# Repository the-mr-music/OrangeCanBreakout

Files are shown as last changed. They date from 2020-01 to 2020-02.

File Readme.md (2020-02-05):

# Orange PI CAN Breakout


T. Music - 01/2020

## Project Status

```
PCB Design Complete - Next up is assembly and testing
```

## Introduction

Some time ago I had ordered myself a Raspberry Pi Zero with the intention to use it as a wireless debugger. The performance of it and the system in general however did not live up to my expected standards, so I had decided to give another single board computer a shot. The requirements whilst picking were easy integreatibility (USB on pinheaders), sufficiently high computational power (something the rpi zero somewhat lacked) and naturally - WiFi. In the end the Orange Pi Zero Plus 2 (Allwinner H5 core) won and was ordered.

On top of that I thought about extending the capability of said system through optional modules, which can be addressed through a python api running on the orange pi. One criteria was to provide somewhat sufficient data rate for hobbyist use cases and to keep the hardware overhead low. After reading through a few bus systems and protocols I reached the decision to use CAN bus. Cheap controllers by ST have already CAN controllers built in and require only a transceiver in the range of a few cents. These STM32 support data rates up to 1 Mbit/s, enough for small amounts of measurement data as well as control messages.
If one needs higher data rates, the CAN FD standard increases the message's data bitrate to up to 8 Mbit/s. Whilst CAN FD is backwards compatible to regular CAN, upwards compatibility is not given, therefore legacy and FD nodes should not be mixed on one bus.

## Description
< write me >

## Design Notes

Only wanted one distributor. Due to my previous positive experiences, I again went for LCSC.  
With the design finalised, the PCB was sent off to JLCPCB.

## Schematic
Click here to open the [Schematic Revision 1](Production_Data_Rev_1/can_breakout_pcb_rev1.pdf).

## Renders

### Front
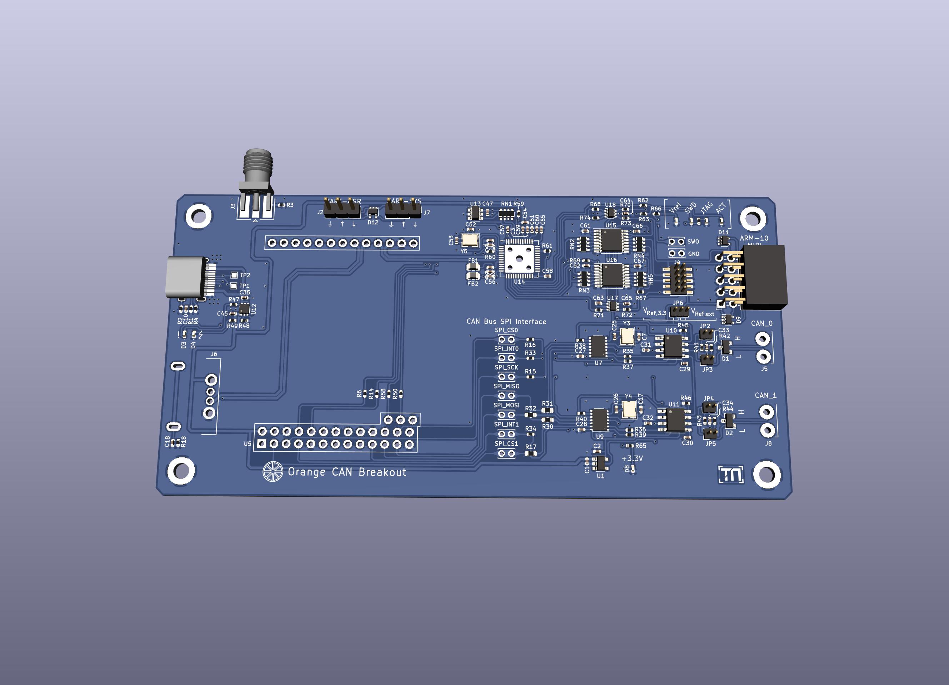
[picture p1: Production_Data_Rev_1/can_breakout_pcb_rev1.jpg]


### Back
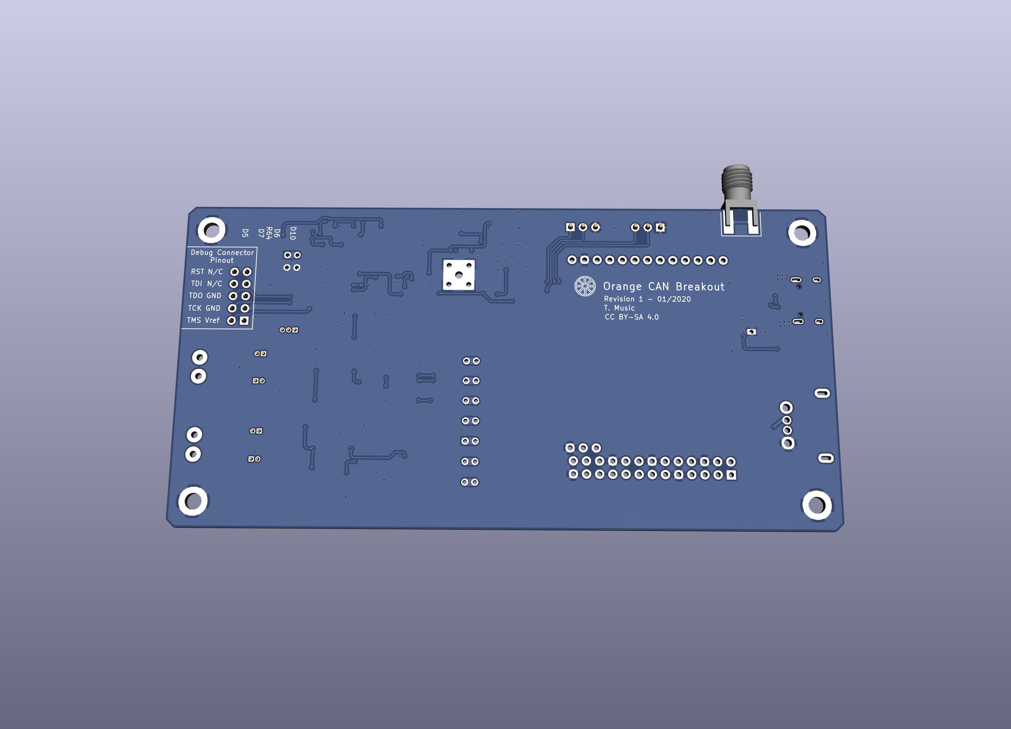
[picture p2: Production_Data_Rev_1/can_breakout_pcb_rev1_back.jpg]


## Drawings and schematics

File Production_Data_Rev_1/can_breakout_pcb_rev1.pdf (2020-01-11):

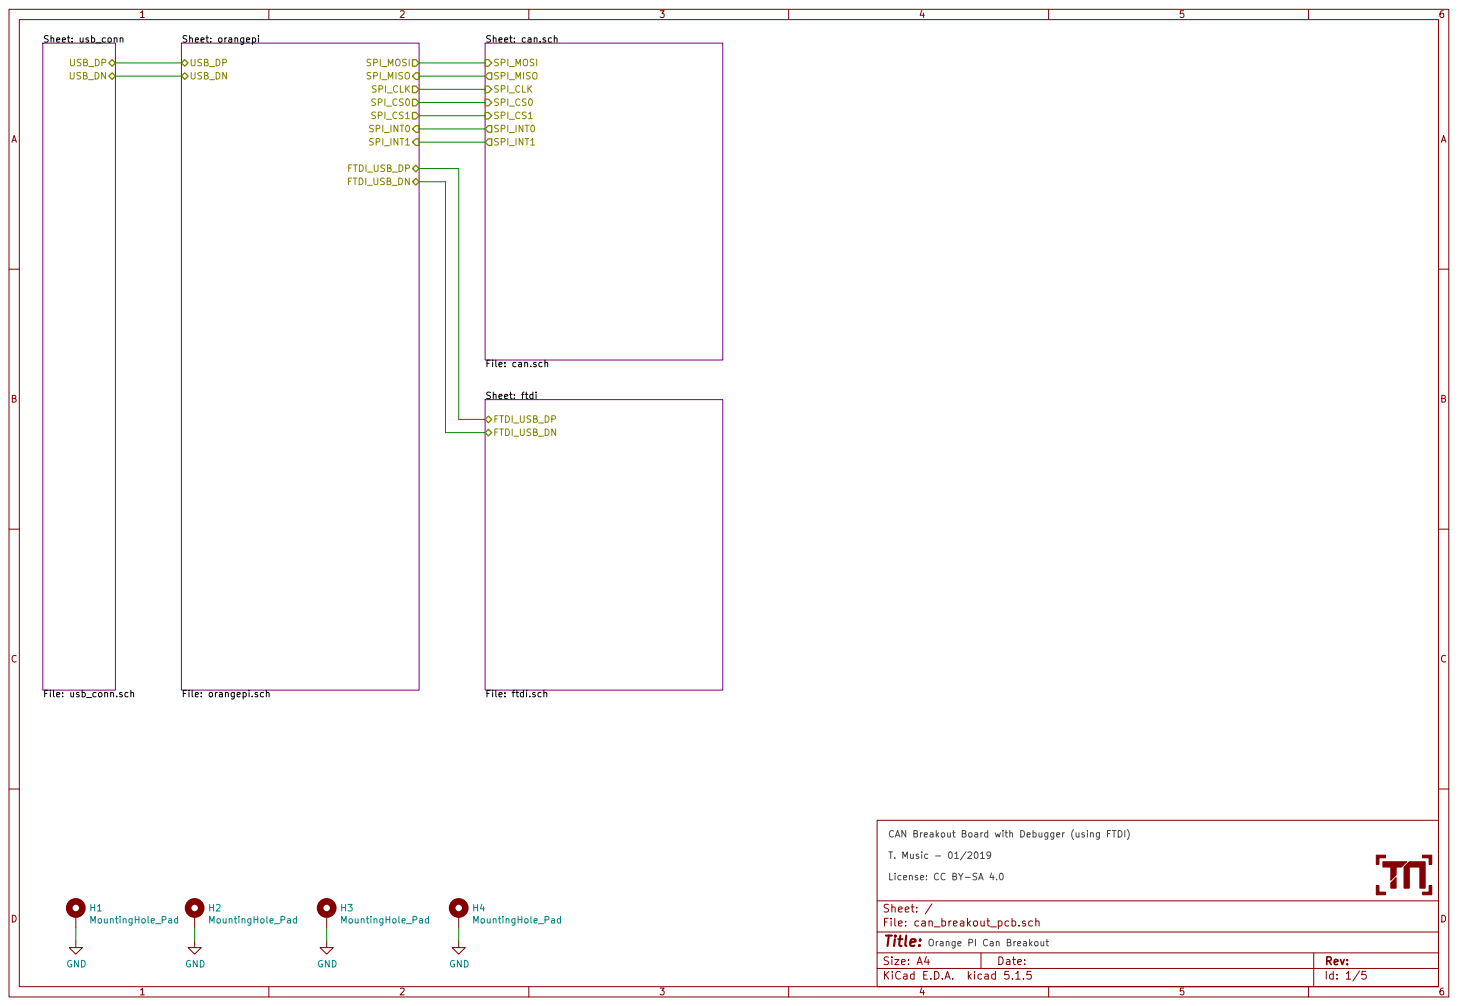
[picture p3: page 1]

Sheet: can.sch File: can.sch SPI_MOSI SPI_MISO

CAN Breakout Board with Debugger (using FTDI) T. Music - 01/2019

License: CC BY-SA 4.0

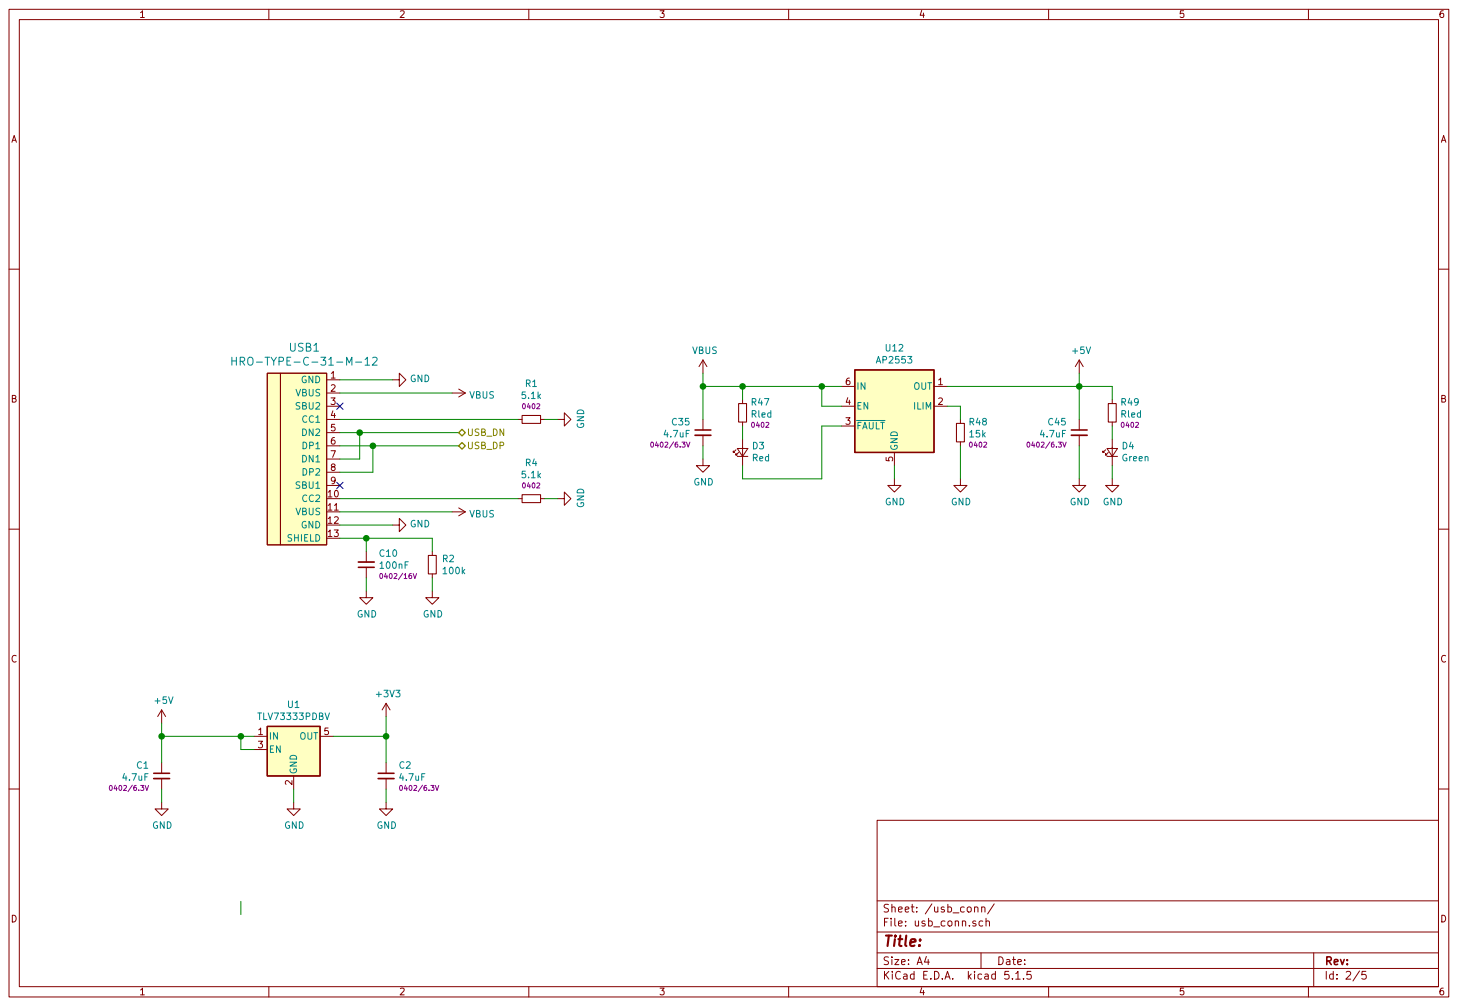
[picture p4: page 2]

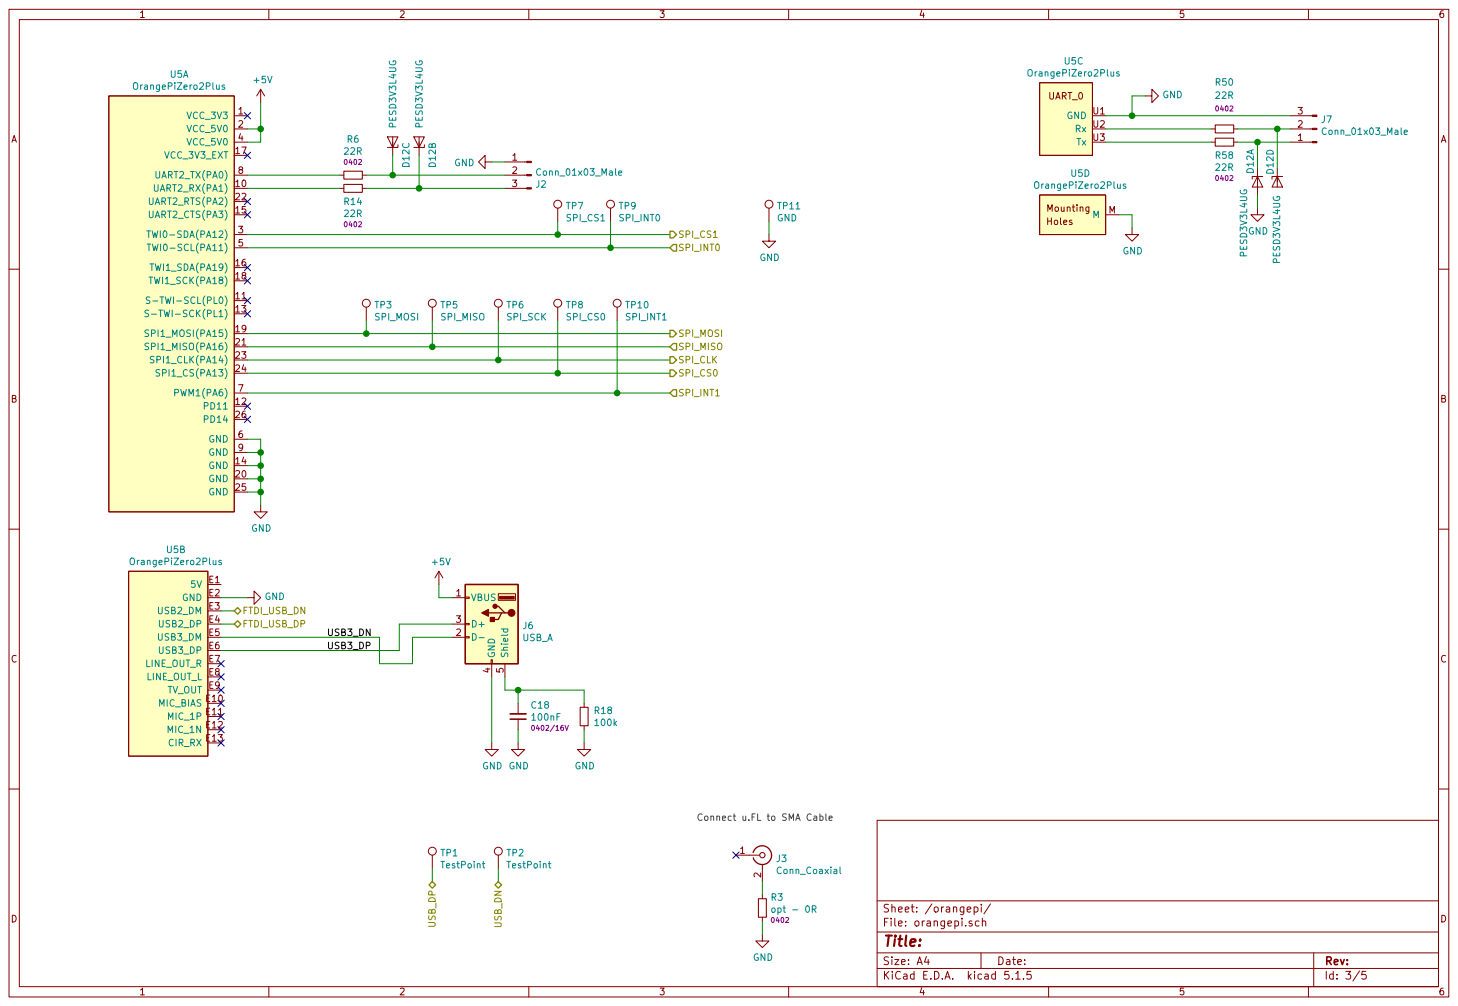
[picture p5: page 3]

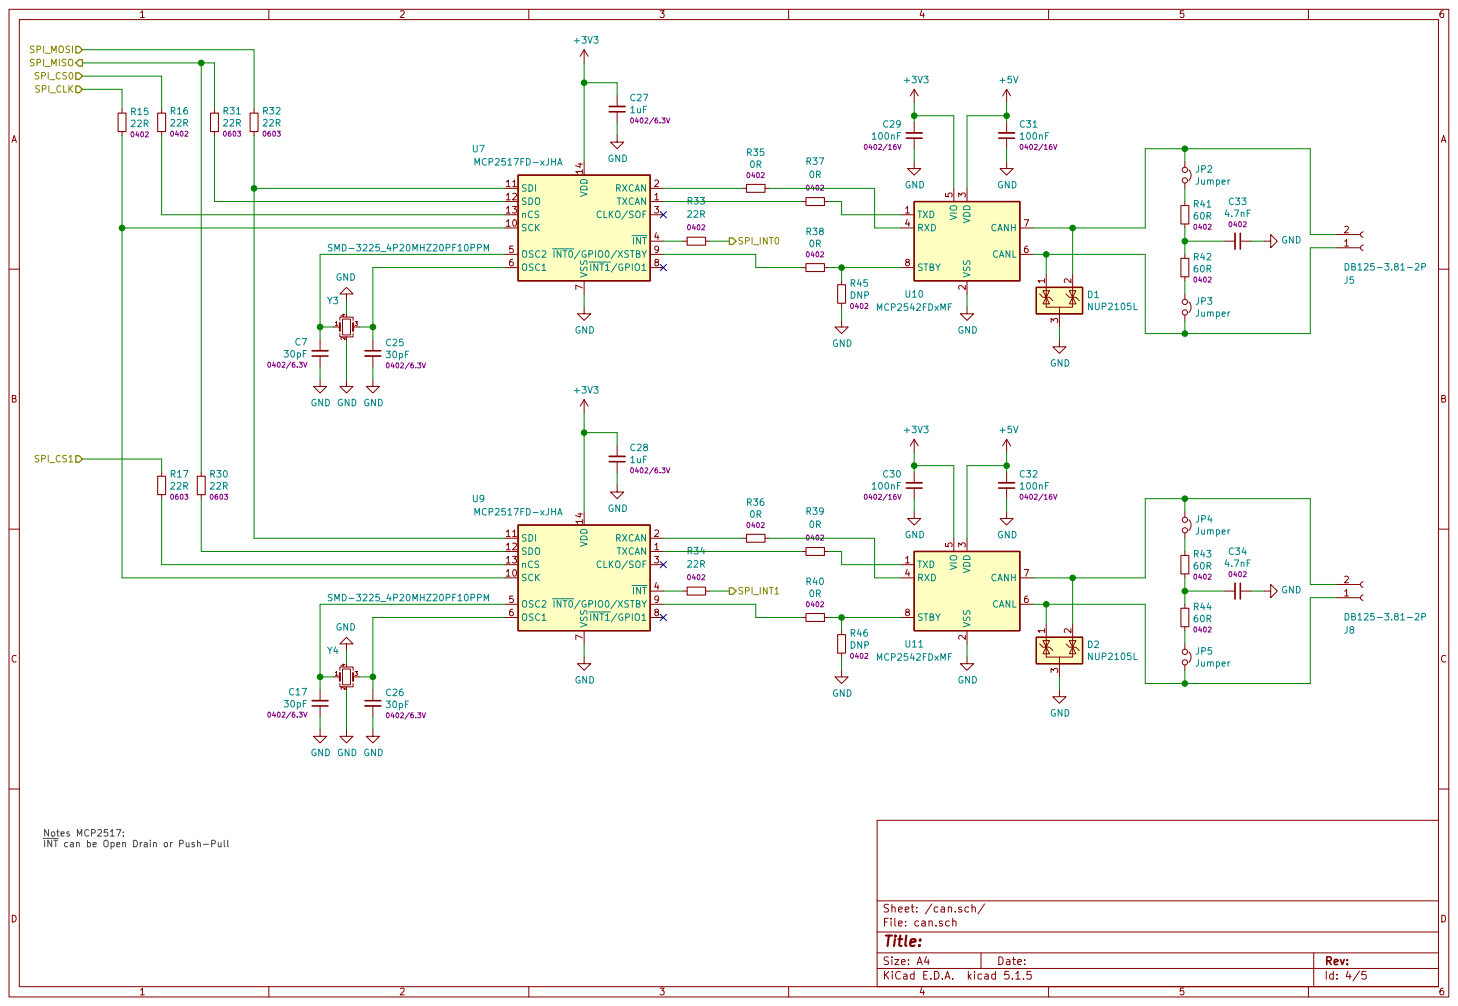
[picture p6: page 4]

5 CANL 6 CANH 7 STBY 8U10 MCP2542FDxMF GND

INT can be Open Drain or Push-Pull

Id: 4/5 Title: File: can.sch Sheet: /can.sch/

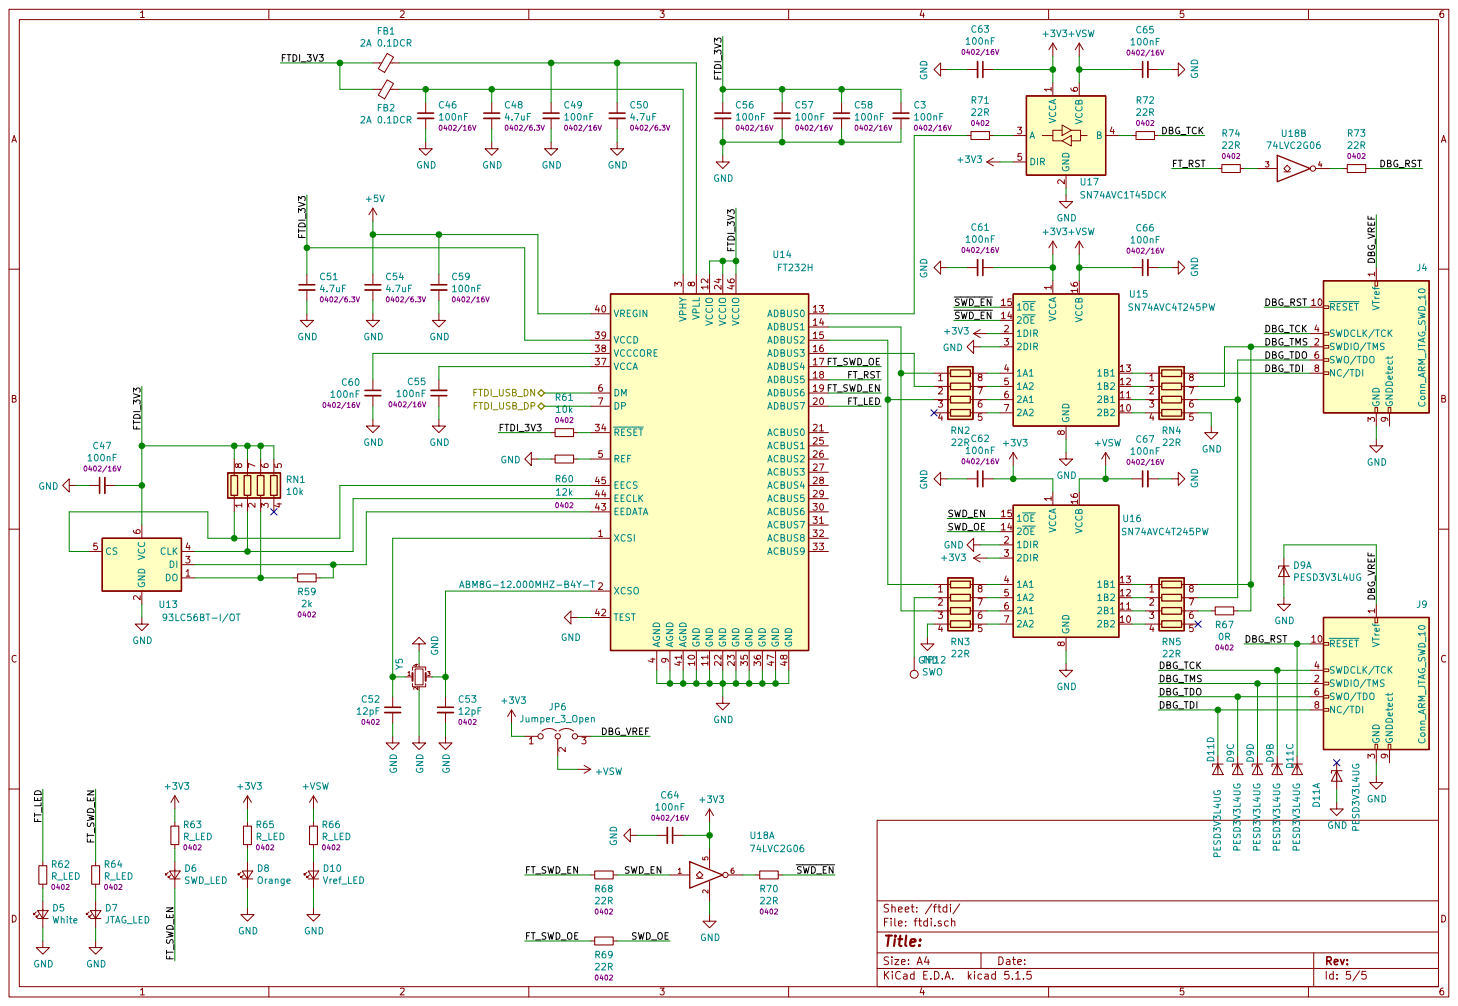
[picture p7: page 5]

9 U14 FT232H GND GND GND GND

4 VREGIN 40 AGND 41 TEST 42 EEDATA 43 EECLK 44 EECS 45 VCCIO 46 GND 47 GND 48 REF 5 DM 6 DP 7 VPLL

3 ACBUS6 30 ACBUS7 31 ACBUS8 32 ACBUS9 33 RESET 34 GND 35 GND 36 VCCA 37 VCCCORE 38 VCCD 39 AGND

3 SWDCLK/TCK 4 SWO/TDO 6 NC/TDI 8 GNDDetect 9

2 DI 3 CLK 4 CS 5 VCC

Id: 5/5 Title: File: ftdi.sch Sheet: /ftdi/

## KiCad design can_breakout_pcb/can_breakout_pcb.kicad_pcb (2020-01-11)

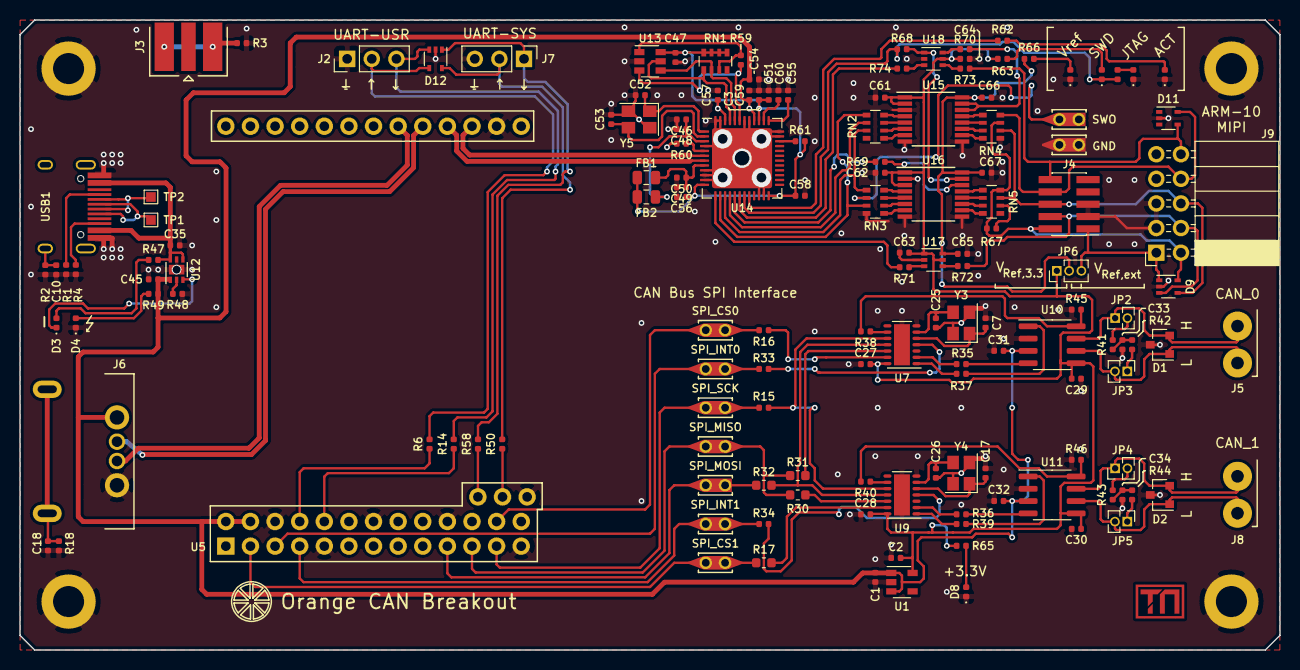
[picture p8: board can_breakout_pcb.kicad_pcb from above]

Board: 2 copper layers, 130.0 x 65.0 mm, 154 parts (0 on the bottom side), 127 nets.

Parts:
C1, C2, C35, C45, C48, C50, C51, C54: 4.7uF; C_0402_1005Metric
C3, C10, C18, C29, C30, C31, C32, C46, C47, C49, C55, C56, C57, C58, C59, C60, C61, C62, C63, C64, C65, C66, C67: 100nF; C_0402_1005Metric
C7, C17, C25, C26: 30pF; C_0402_1005Metric
C27, C28: 1uF; C_0402_1005Metric
C33, C34: 4.7nF; C_0402_1005Metric
C52, C53: 12pF; C_0402_1005Metric
D1, D2: NUP2105L; SOT-23
D3: Red; LED_0402_1005Metric
D4: Green; LED_0402_1005Metric
D5: White; LED_0402_1005Metric
D6: SWD_LED; LED_0402_1005Metric
D7: JTAG_LED; LED_0402_1005Metric
D8: Orange; LED_0402_1005Metric
D9, D11, D12: PESD3V3L4UG; SOT-353_SC-70-5
D10: Vref_LED; LED_0402_1005Metric
FB1, FB2: 2A 0.1DCR; L_0805_2012Metric
H1, H2, H3, H4: MountingHole_Pad; MountingHole_3.2mm_M3_DIN965_Pad
J2, J7: Conn_01x03_Male; PinHeader_1x03_P2.54mm_Vertical
J3: Conn_Coaxial; SMA_6x6mm_MidMount
J4: Conn_ARM_JTAG_SWD_10; PinHeader_2x05_P1.27mm_Vertical_SMD
J5, J8: DB125-3.81-2P
J6: USB_A; USB_AF_DIP
J9: Conn_ARM_JTAG_SWD_10; PinSocket_2x05_P2.54mm_Horizontal
JP2, JP3, JP4, JP5: Jumper; PinHeader_1x02_P1.27mm_Vertical
JP6: Jumper_3_Open; PinHeader_1x03_P1.27mm_Vertical
LOGO1: Logo_TM_small; TM_logo
R1, R4: 5.1k; R_0402_1005Metric
R2, R18: 100k; R_0402_1005Metric
R3: opt - 0R; R_0402_1005Metric
R6, R14, R15, R16, R33, R34, R50, R58, R68, R69, R70, R71, R72, R73, R74: 22R; R_0402_1005Metric
R17, R30, R31, R32: 22R; R_0603_1608Metric
R35, R36, R37, R38, R39, R40, R67: 0R; R_0402_1005Metric
R41, R42, R43, R44: 60R; R_0402_1005Metric
R45, R46: DNP; R_0402_1005Metric
R47, R49: Rled; R_0402_1005Metric
R48: 15k; R_0402_1005Metric
R59: 2k; R_0402_1005Metric
R60: 12k; R_0402_1005Metric
R61: 10k; R_0402_1005Metric
R62, R63, R64, R65, R66: R_LED; R_0402_1005Metric
RN1: 10k; R_Array_Convex_4x0603
RN2, RN3, RN4, RN5: 22R; R_Array_Convex_4x0603
TP1, TP2: TestPoint; TestPoint_Pad_1.0x1.0mm
TP3: SPI_MOSI; TestPadClip_0.25
TP5: SPI_MISO; TestPadClip_0.25_Passthrough
TP6: SPI_SCK; TestPadClip_0.25_Passthrough
TP7: SPI_CS1; TestPadClip_0.25_Passthrough
TP8: SPI_CS0; TestPadClip_0.25_Passthrough
TP9: SPI_INT0; TestPadClip_0.25_Passthrough
TP10: SPI_INT1; TestPadClip_0.25_Passthrough
TP11: GND; TestPadClip_0.25
TP12: SWO; TestPadClip_0.25
U1: TLV73333PDBV; SOT-23-5
U5: OrangePiZero2Plus; OPi_Zero_plus_2_NoMountHoles
U7, U9: MCP2517FD-xJHA; DFN-14-1EP_3x4.5mm_P0.65mm_EP1.65x4.25mm
U10, U11: MCP2542FDxMF; SOIC-8_3.9x4.9mm_P1.27mm
U12: AP2553; DFN-6-1EP_2x2mm_P0.65mm_EP1x1.6mm
U13: 93LC56BT-I/OT; SOT-23-6
U14: FT232H; QFN-48-1EP_8x8mm_P0.5mm_EP6.2x6.2mm
U15, U16: SN74AVC4T245PW; TSSOP-16_4.4x5mm_P0.65mm
U17: SN74AVC1T45DCK; SOT-363_SC-70-6
U18: 74LVC2G06; SOT-363_SC-70-6
USB1: HRO-TYPE-C-31-M-12; HRO-TYPE-C-31-M-12-HandSoldering
Y3, Y4: SMD-3225_4P20MHZ20PF10PPM; Crystal_SMD_3225-4Pin_3.2x2.5mm
Y5: ABM8G-12.000MHZ-B4Y-T; Crystal_SMD_Abracon_ABM8G-4Pin_3.2x2.5mm

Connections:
+3V3: C2.1, C27.2, C28.2, C29.2, C30.2, C61.1, C62.1, C63.1, C64.1, JP6.1, R63.1, R65.1, U1.5, U7.14, U9.14, U10.5, U11.5, U15.1, U15.2, U16.1, U16.3, U17.1, U17.5, U18.5
+5V: C1.1, C31.2, C32.2, C45.1, C54.1, C59.1, J6.1, R49.1, U1.1, U1.3, U5.2, U5.4, U10.3, U11.3, U12.1, U14.40
+VSW: C65.1, C66.1, C67.1, JP6.2, R66.1, U15.16, U16.16, U17.6
/can.sch/SPI_CLK: R15.1, TP6.1, U5.23
/can.sch/SPI_CS0: R16.2, TP8.1, U5.24
/can.sch/SPI_CS1: R17.2, TP7.1, U5.3
/can.sch/SPI_INT0: R33.2, TP9.1, U5.5
/can.sch/SPI_INT1: R34.2, TP10.1, U5.7
/can.sch/SPI_MISO: R30.2, R31.2, TP5.1, U5.21
/can.sch/SPI_MOSI: R32.2, TP3.1, U5.19
/ftdi/DBG_RST: D11.4, J4.10, J9.10, R73.1
/ftdi/DBG_TCK: D9.3, J4.4, J9.4, R72.1
/ftdi/DBG_TDI: D11.5, J4.8, J9.8, RN4.8
/ftdi/DBG_TDO: D9.4, J4.6, J9.6, RN4.6, RN5.7
/ftdi/DBG_TMS: D9.5, J4.2, J9.2, R67.1, RN4.7, RN5.8
/ftdi/DBG_VREF: D9.1, J4.1, J9.1, JP6.3
/ftdi/FTDI_3V3: C3.1, C47.2, C51.1, C56.1, C57.1, C58.1, FB1.1, FB2.1, R61.2, RN1.5, RN1.6, RN1.7, RN1.8, U13.6, U14.12, U14.24, U14.39, U14.46
/ftdi/FTDI_USB_DN: U5.E3, U14.6
/ftdi/FTDI_USB_DP: U5.E4, U14.7
/ftdi/FT_LED: R62.1, U14.20
/ftdi/FT_RST: R74.2, U14.18
/ftdi/FT_SWD_EN: D6.1, R64.1, R68.2, U14.19
/ftdi/FT_SWD_OE: R69.2, U14.17
/ftdi/SWD_EN: R68.1, U16.15, U18.1
/ftdi/SWD_OE: R69.1, U16.14
/ftdi/~SWD_EN~: R70.1, U15.14, U15.15
/orangepi/USB3_DN: J6.2, U5.E5
/orangepi/USB3_DP: J6.3, U5.E6
/orangepi/USB_DN: TP2.1, USB1.5, USB1.7
/orangepi/USB_DP: TP1.1, USB1.6, USB1.8
GND: C1.2, C2.2, C3.2, C7.1, C10.1, C17.1, C18.1, C25.2, C26.2, C27.1, C28.1, C29.1, C30.1, C31.1, C32.1, C33.1, C34.1, C35.2, C45.2, C46.2, C47.1, C48.2, C49.2, C50.2, C51.2, C52.2, C53.2, C54.2, C55.1, C56.2, C57.2, C58.2, C59.2, C60.2, C61.2, C62.2, C63.2, C64.2, C65.2, C66.2, C67.2, D1.3, D2.3, D4.1, D5.1, D7.1, D8.1, D9.2, D10.1, D11.2, D12.2, H1.1, H2.1, H3.1, H4.1, J2.1, J4.3, J4.5, J6.4, J7.3, J9.3, J9.5, R1.2, R2.2, R3.2, R4.2, R18.2, R45.2, R46.2, R48.2, R60.2, RN3.4, RN4.5, TP11.1, U1.2, U5.6, U5.9, U5.14, U5.20, U5.25, U5.E2, U5.U1, U7.7, U7.15, U9.7, U9.15, U10.2, U11.2, U12.5, U12.7, U13.2, U14.4, U14.9, U14.10, U14.11, U14.22, U14.23, U14.35, U14.36, U14.41, U14.42, U14.47, U14.48, U14.49, U15.3, U15.8, U15.9, U16.2, U16.8, U16.9, U17.2, U18.2, USB1.1, USB1.12, Y3.2, Y3.4, Y4.2, Y4.4, Y5.2, Y5.4
unnamed: C7.2, U7.5, Y3.1
unnamed: C10.2, R2.1, USB1.13
unnamed: C17.2, U9.5, Y4.1
unnamed: C18.2, J6.5, R18.1
unnamed: C25.1, U7.6, Y3.3
unnamed: C26.1, U9.6, Y4.3
unnamed: C33.2, R41.2, R42.1
unnamed: C34.2, R43.2, R44.1
unnamed: C46.1, C48.1, FB2.2, U14.3
unnamed: C49.1, C50.1, FB1.2, U14.8
unnamed: C52.1, U14.1, Y5.1
unnamed: C53.1, U14.2, Y5.3
unnamed: C55.2, U14.37
unnamed: C60.1, U14.38
unnamed: D1.1, J5.1, JP3.2, U10.6
unnamed: D1.2, J5.2, JP2.1, U10.7
unnamed: D2.1, J8.1, JP5.2, U11.6
unnamed: D2.2, J8.2, JP4.1, U11.7
unnamed: D3.1, U12.3
unnamed: D3.2, R47.2
unnamed: D4.2, R49.2
unnamed: D5.2, R62.2
unnamed: D6.2, R63.2
unnamed: D7.2, R64.2
unnamed: D8.2, R65.2
unnamed: D10.2, R66.2
unnamed: D12.1, J7.1, R58.2
unnamed: D12.3, J2.3, R14.2
unnamed: D12.4, J2.2, R6.2
unnamed: D12.5, J7.2, R50.2
unnamed: J3.2, R3.1
unnamed: JP2.2, R41.1
unnamed: JP3.1, R42.2
unnamed: JP4.2, R43.1
unnamed: JP5.1, R44.2
unnamed: R1.1, USB1.4
unnamed: R4.1, USB1.10
unnamed: R6.1, U5.8
unnamed: R14.1, U5.10
unnamed: R15.2, U7.10, U9.10
unnamed: R16.1, U7.13
unnamed: R17.1, U9.13
unnamed: R30.1, U9.12
unnamed: R31.1, U7.12
unnamed: R32.1, U7.11, U9.11
unnamed: R33.1, U7.4
unnamed: R34.1, U9.4
unnamed: R35.1, U7.2
unnamed: R35.2, U10.4
unnamed: R36.1, U9.2
unnamed: R36.2, U11.4
unnamed: R37.1, U7.1
unnamed: R37.2, U10.1
unnamed: R38.1, U7.9
unnamed: R38.2, R45.1, U10.8
unnamed: R39.1, U9.1
unnamed: R39.2, U11.1
unnamed: R40.1, U9.9
unnamed: R40.2, R46.1, U11.8
unnamed: R48.1, U12.2
unnamed: R50.1, U5.U2
unnamed: R58.1, U5.U3
unnamed: R59.1, U13.3, U14.43
unnamed: R59.2, RN1.3, U13.1
unnamed: R60.1, U14.5
unnamed: R61.1, U14.34
unnamed: R67.2, RN5.6
unnamed: R70.2, U18.6
unnamed: R71.1, U17.3
unnamed: R71.2, U14.13
unnamed: R72.2, U17.4
unnamed: R73.2, U18.4
unnamed: R74.1, U18.3
unnamed: RN1.1, U13.5, U14.45
unnamed: RN1.2, U13.4, U14.44
unnamed: RN2.1, RN3.3, U14.14
unnamed: RN2.2, U14.16
unnamed: RN2.3, RN3.1, U14.15
unnamed: RN2.5, U15.7
unnamed: RN2.6, U15.6
unnamed: RN2.7, U15.5
unnamed: RN2.8, U15.4
unnamed: RN3.2, TP12.1
unnamed: RN3.5, U16.7
unnamed: RN3.6, U16.6
unnamed: RN3.7, U16.5
unnamed: RN3.8, U16.4
unnamed: RN4.1, U15.13
unnamed: RN4.2, U15.12
unnamed: RN4.3, U15.11
unnamed: RN4.4, U15.10
unnamed: RN5.1, U16.13
unnamed: RN5.2, U16.12
unnamed: RN5.3, U16.11
unnamed: RN5.4, U16.10
VBUS: C35.1, R47.1, U12.4, U12.6, USB1.2, USB1.11

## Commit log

2020-01-11 Added gerber files for revision 1
    [can_breakout_pcb-B_Cu.gbr, can_breakout_pcb-B_Mask.gbr, can_breakout_pcb-B_Paste.gbr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]
2020-01-11 Added PCB Rev. 1
    [can.sch, can_breakout_pcb.kicad_pcb, can_breakout_pcb.sch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]
